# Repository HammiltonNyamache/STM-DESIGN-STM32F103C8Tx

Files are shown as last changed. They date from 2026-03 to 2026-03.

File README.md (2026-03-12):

# STM-DESIGN-STM32F103C8Tx
Custom STM32F103C8T6 development board designed in KiCad. The design includes USB power input, AMS1117 3.3V regulation, SWD programming interface, UART and I2C headers, external 16 MHz crystal oscillator, and proper decoupling and filtering for stable MCU operation.

## Overview
This repository contains the KiCad design files for a custom STM32F103C8T6 development board. The board integrates power regulation, USB connectivity, programming/debugging interfaces, and communication headers for embedded development.

The project was designed using KiCad 9 and demonstrates the complete workflow of schematic design, PCB layout, and manufacturing file generation.

## Features
- STM32F103C8T6 ARM Cortex-M3 microcontroller
- USB Micro-B interface
- 3.3V voltage regulation using AMS1117
- 16 MHz external crystal oscillator
- SWD programming and debugging interface
- UART communication header
- I2C communication interface
- Power indication LED
- Proper decoupling and analog filtering
- Mounting holes for mechanical support

## Hardware Architecture

### Power Supply
The board is powered through a USB Micro-B connector. The input voltage (VBUS) is regulated to 3.3V using an AMS1117-3.3 linear voltage regulator.  
Filtering capacitors are used to stabilize the supply voltage and reduce noise.

### Microcontroller
The main controller used is the STM32F103C8T6, a 32-bit ARM Cortex-M3 microcontroller.  
It operates at 3.3V and supports multiple communication peripherals including UART, I2C, SPI, and USB.

### Clock System
An external 16 MHz crystal oscillator is connected to the MCU to provide a stable clock source.  
Two load capacitors are used to stabilize the oscillator.

### USB Interface
The microcontroller is connected to a USB Micro-B connector through the D+ and D- lines.  
A pull-up resistor is used to enable USB device detection.

### Debugging Interface
An SWD (Serial Wire Debug) interface is provided for programming and debugging using tools such as:

- ST-Link
- OpenOCD
- STM32CubeProgrammer

### Communication Interfaces
The board exposes communication headers for external peripherals:

**UART**
- TX
- RX
- GND
- 3.3V

**I2C**
- SDA
- SCL
- GND
- 3.3V

### Analog Power Filtering
A ferrite bead and filtering capacitors are used to isolate the analog supply (VDDA) from digital noise.

### Decoupling
Multiple decoupling capacitors are placed near the MCU power pins to ensure stable operation.

## Tools Used
- KiCad 9.0
- STM32F103C8T6 Microcontroller
- AMS1117-3.3 Voltage Regulator

## Applications
This board can be used for:

- Embedded systems development
- STM32 firmware experimentation
- Learning ARM Cortex-M microcontrollers
- Rapid prototyping
- Educational embedded electronics projects

## Author
Designed as part of an embedded hardware design project by HAMMILTON NYAMACHE  using KiCad.

## PCB Design
### Shcematic
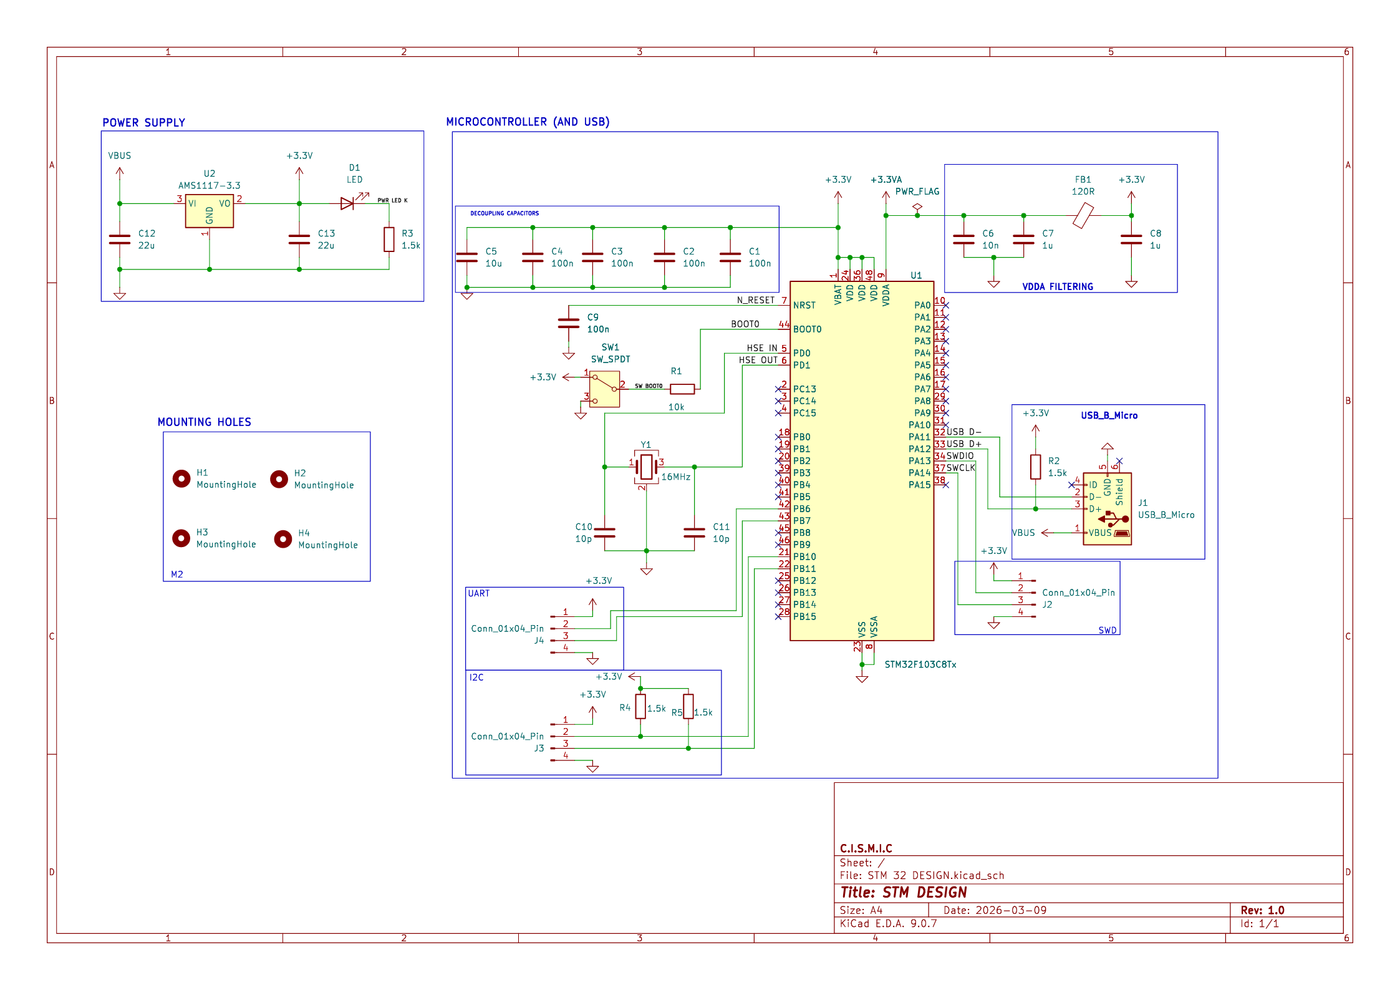
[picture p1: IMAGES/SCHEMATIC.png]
Shematic Diagram


### Top Layer
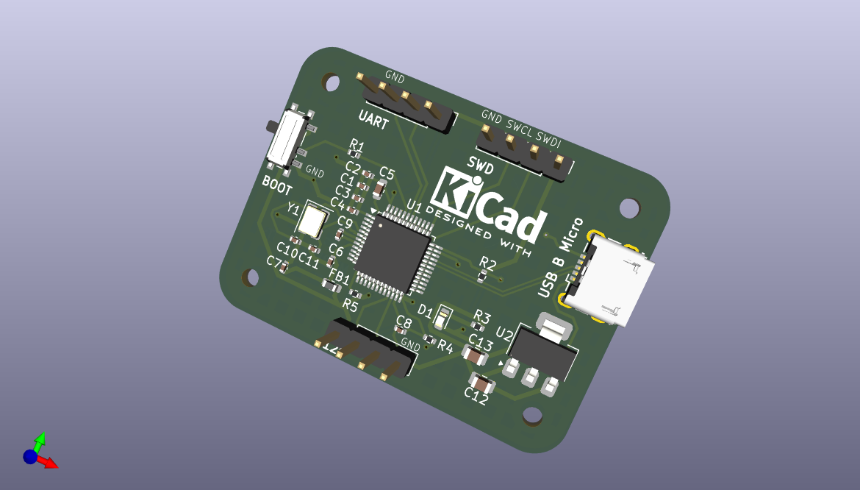
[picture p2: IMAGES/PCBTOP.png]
Top PCB


### Bottom Layer
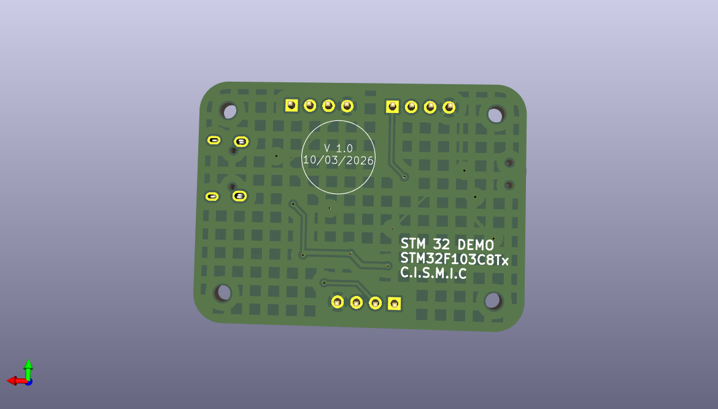
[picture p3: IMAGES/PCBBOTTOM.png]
Bottom PCB


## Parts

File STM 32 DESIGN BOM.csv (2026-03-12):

Comment | Designator | Footprint | JLCPCB Part
100n | C1,C2,C3,C4,C9 | Capacitor_SMD:C_0402_1005Metric | C1525
10u | C5 | Capacitor_SMD:C_0603_1608Metric | C1691
10n | C6 | Capacitor_SMD:C_0402_1005Metric | C1524
1u | C7,C8 | Capacitor_SMD:C_0402_1005Metric | C14445
10p | C10,C11 | Capacitor_SMD:C_0402_1005Metric | C32949
22u | C12,C13 | Capacitor_SMD:C_0805_2012Metric | C5674
LED | D1 | LED_SMD:LED_0603_1608Metric | C2286
120R | FB1 | Inductor_SMD:L_0603_1608Metric | C160983
16MHz | Y1 | Crystal:Crystal_SMD_3225-4Pin_3.2x2.5mm | C518162
USB_B_Micro | J1 | Connector_USB:USB_Micro-B_Wuerth_629105150521 | C2894326
Conn_01x04_Pin | J2,J3,J4 | Connector_PinHeader_2.54mm:PinHeader_1x04_P2.54mm_Vertical | C2905435
10k | R1 | Resistor_SMD:R_0402_1005Metric | C22356213
1.5k | R2,R3,R4,R5 | Resistor_SMD:R_0402_1005Metric | C22369162
SW_SPDT | SW1 | Button_Switch_SMD:SW_SPDT_PCM12 | C221841
STM32F103C8Tx | U1 | Package_QFP:LQFP-48_7x7mm_P0.5mm | C8734
AMS1117-3.3 | U2 | Package_TO_SOT_SMD:SOT-223-3_TabPin2 | C347222

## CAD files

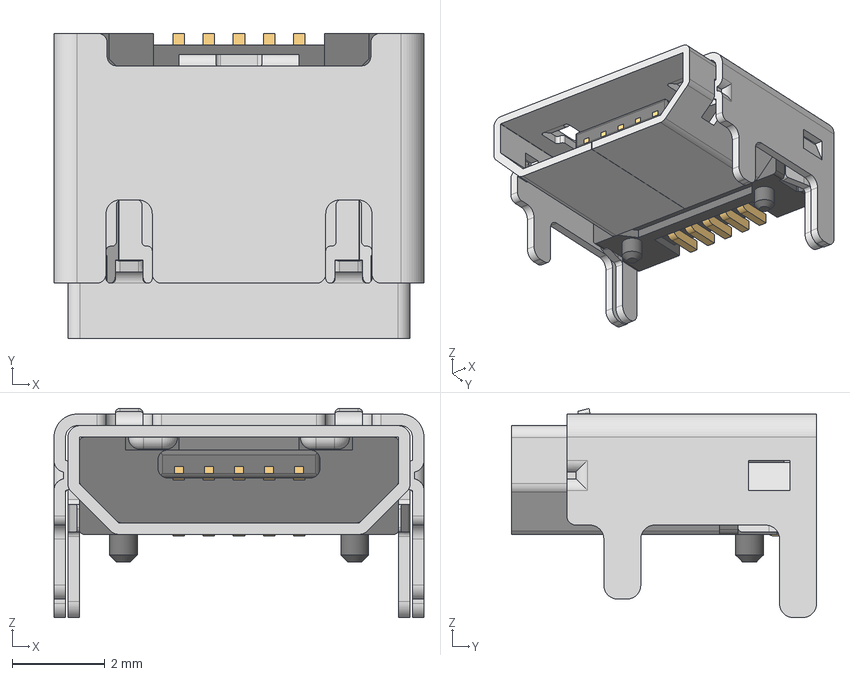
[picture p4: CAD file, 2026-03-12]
629105150521 (rev1).stp
8.00 x 6.60 x 4.52 mm
629105150521_Housing
629105150521_Pin1 x 4
629105150521_Pin2
629105150521_Shielding2
629105150521_Shielding

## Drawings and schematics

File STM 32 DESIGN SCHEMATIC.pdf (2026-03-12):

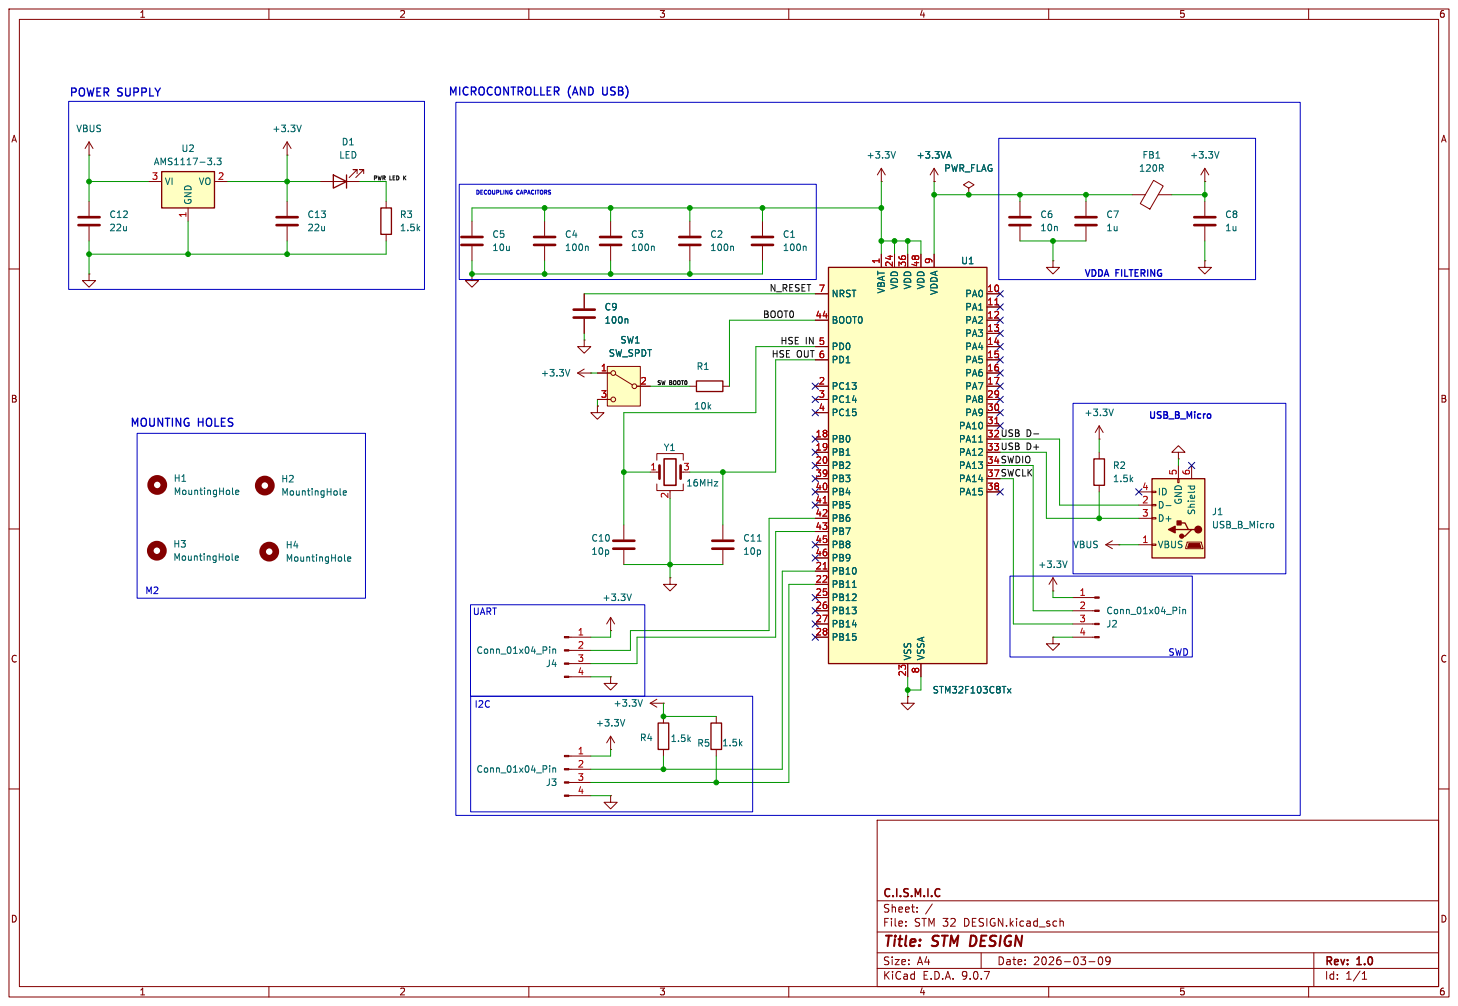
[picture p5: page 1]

1 VDD 24 VDD 36 VSS 23 VDD 48 VSSA

Id: 1/1 Title: STM DESIGN

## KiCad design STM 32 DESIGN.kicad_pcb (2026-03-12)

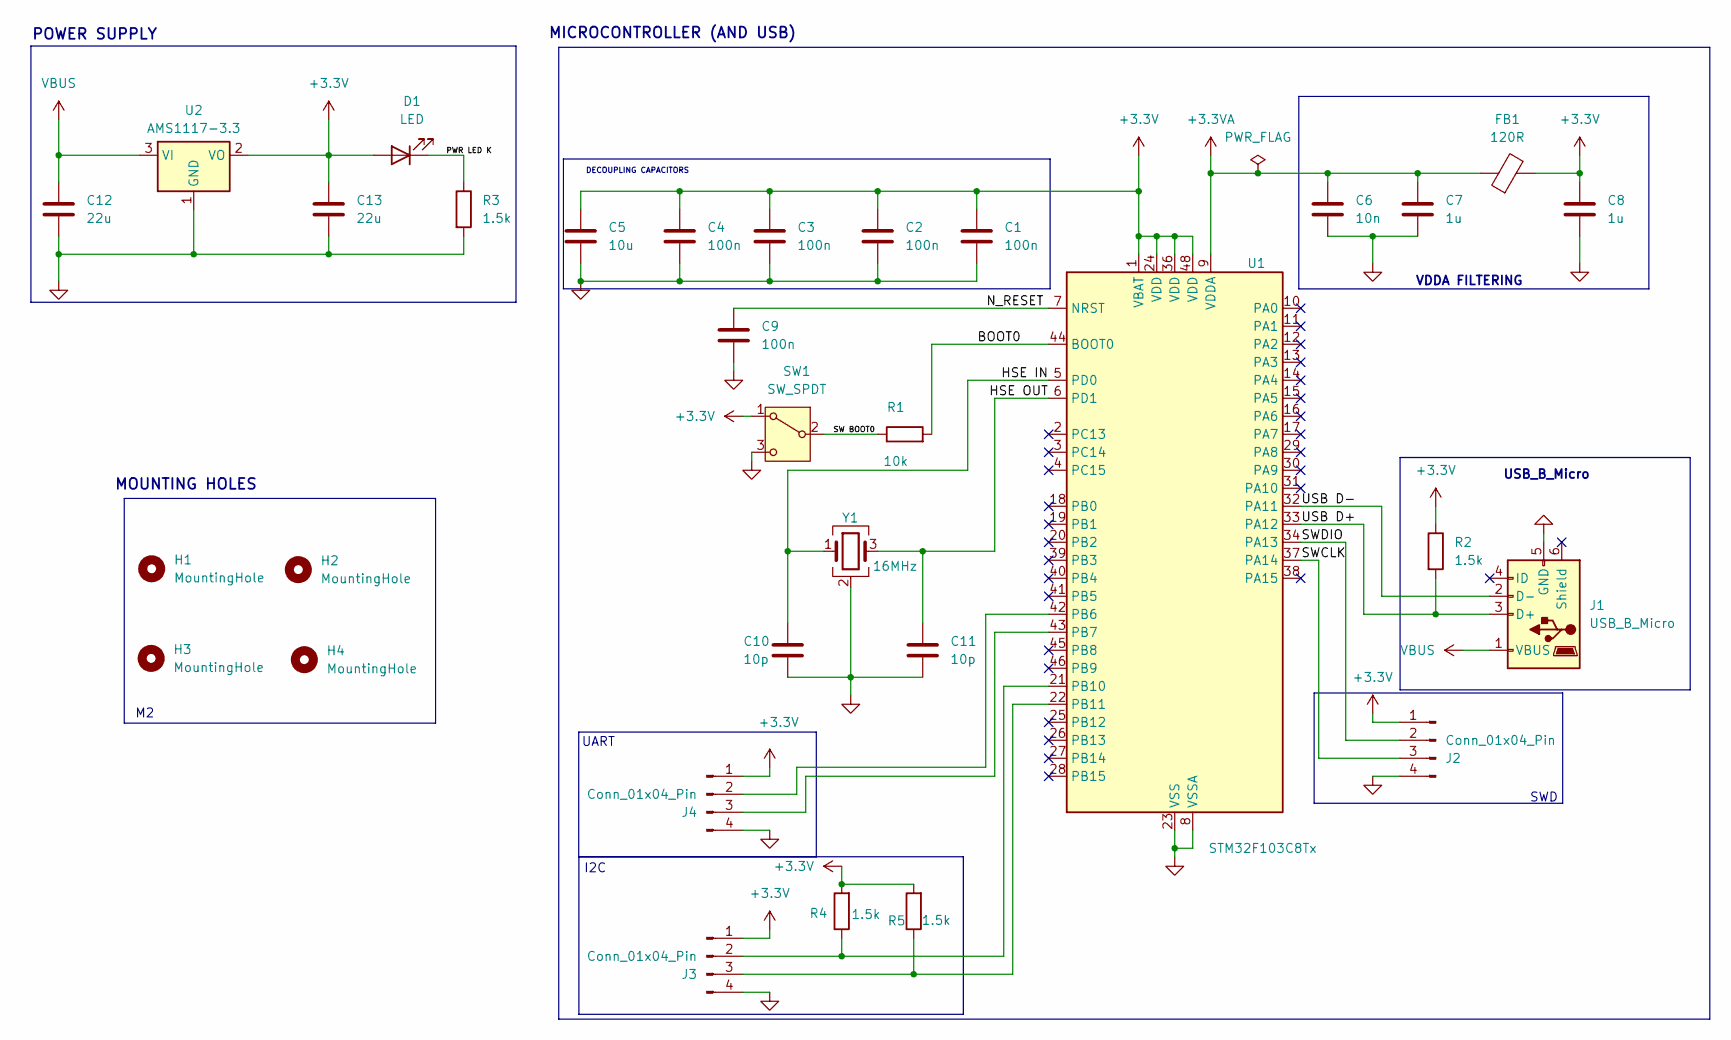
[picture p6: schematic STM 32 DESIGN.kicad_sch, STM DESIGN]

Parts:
C1, C2, C3, C4, C9: 100n; C_0402_1005Metric
C5: 10u; C_0603_1608Metric
C6: 10n; C_0402_1005Metric
C7, C8: 1u; C_0402_1005Metric
C10, C11: 10p; C_0402_1005Metric
C12, C13: 22u; C_0805_2012Metric
D1: LED; LED_0603_1608Metric
FB1: 120R; L_0603_1608Metric
H1, H2, H3, H4: MountingHole; MountingHole_2.2mm_M2
J1: USB_B_Micro; USB_Micro-B_Wuerth_629105150521
J2, J3, J4: Conn_01x04_Pin; PinHeader_1x04_P2.54mm_Vertical
R1: 10k; R_0402_1005Metric
R2, R3, R4, R5: 1.5k; R_0402_1005Metric
SW1: SW_SPDT; SW_SPDT_PCM12
U1: STM32F103C8Tx; LQFP-48_7x7mm_P0.5mm
U2: AMS1117-3.3; SOT-223-3_TabPin2
Y1: 16MHz; Crystal_SMD_3225-4Pin_3.2x2.5mm

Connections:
+3.3V: C1.1, C2.1, C3.1, C4.1, C5.1, C8.1, C13.1, D1.2 (A), FB1.2, J2.1, J3.1, J4.1, R2.1, R4.2, R5.2, SW1.1 (A), U1.1 (VBAT), U1.24 (VDD), U1.36 (VDD), U1.48 (VDD), U2.2 (VO)
+3.3VA: C6.1, C7.1, FB1.1, U1.9 (VDDA)
/BOOT0: R1.2, U1.44 (BOOT0)
/HSE IN: C10.1, U1.5 (PD0), Y1.1
/HSE OUT: C11.1, U1.6 (PD1), Y1.3
/N_RESET: C9.1, U1.7 (NRST)
/PWR LED K: D1.1 (K), R3.1
/SW BOOT0: R1.1, SW1.2 (B)
/SWCLK: J2.3, U1.37 (PA14)
/SWDIO: J2.2, U1.34 (PA13)
/USB D+: J1.3 (D+), R2.2, U1.33 (PA12)
/USB D-: J1.2 (D-), U1.32 (PA11)
GND: C1.2, C2.2, C3.2, C4.2, C5.2, C6.2, C7.2, C8.2, C9.2, C10.2, C11.2, C12.2, C13.2, J1.5 (GND), J2.4, J3.4, J4.4, R3.2, SW1.3 (C), U1.8 (VSSA), U1.23 (VSS), U1.35 (VSS), U1.47 (VSS), U2.1 (GND), Y1.2 (G), Y1.4 (G)
unnamed: J3.2, R4.1, U1.21 (PB10)
unnamed: J3.3, R5.1, U1.22 (PB11)
unnamed: J4.2, U1.42 (PB6)
unnamed: J4.3, U1.43 (PB7)
VBUS: C12.1, J1.1 (VBUS), U2.3 (VI)

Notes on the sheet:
POWER SUPPLY
SWD
UART
VDDA FILTERING
USB_B_Micro
DECOUPLING CAPACITORS
MOUNTING HOLES
MICROCONTROLLER (AND USB)
I2C

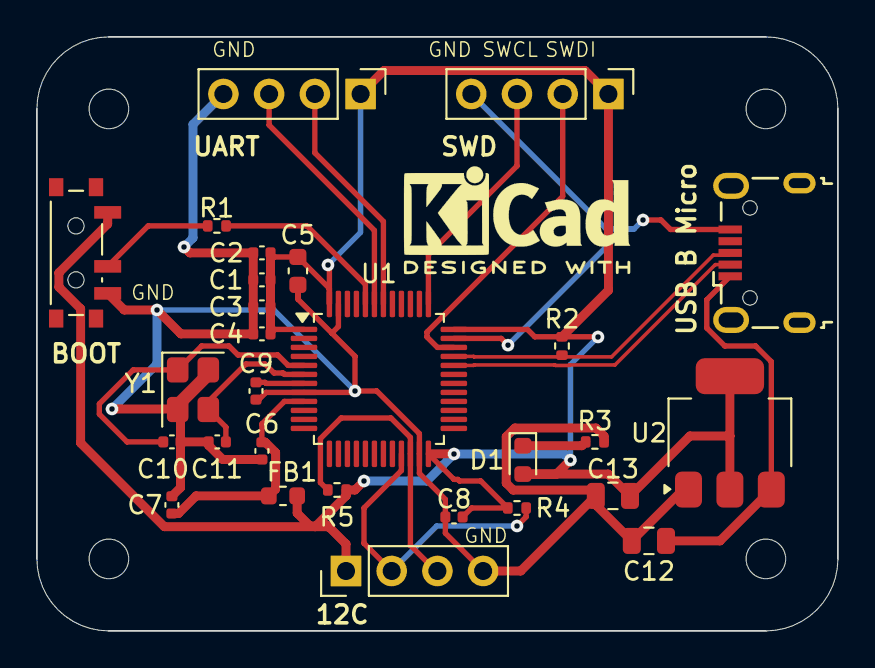
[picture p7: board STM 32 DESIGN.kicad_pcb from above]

Board: 2 copper layers, 44.5 x 33.0 mm, 32 parts (0 on the bottom side), 18 nets.

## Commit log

2026-03-11 Update README with tools, applications, and design info
    Added sections for tools used, applications, author, and PCB design.
2026-03-12 Add schematic section to README
2026-03-12 Update schematic image path in README
